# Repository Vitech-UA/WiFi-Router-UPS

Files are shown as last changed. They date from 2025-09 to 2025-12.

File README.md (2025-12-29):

# WiFi-Router-UPS
**Версія:** 3  
**Призначення:** Резервне живлення для WiFi-роутера та оптоволоконного терміналу (ONT)  
**Оновлення:** Версія 3 розроблена з урахуванням недоліків, виявлених у версії 2  

---
## Технічні характеристики
- **Вхідна напруга:** 8–12 В DC  
- **Максимальний вхідний струм:** 2 А  
- **Тип акумуляторів:** Li-Ion 18650 — 4 шт.  
- **Струм заряджання акумуляторів:** до 2,1 А  

### Вихідні канали
| Канал | Напруга | Струм | Призначення |
|---|---|---|---|
| 1 | 9 В / 12 В | до 1 А | Живлення WiFi-роутера |
| 2 | 9 В / 12 В | до 1 А | Живлення оптоволоконного терміналу |

---
## Зображення плати (v3)
| Верхня сторона (TOP) | Нижня сторона (BOTTOM) |
|---|---|
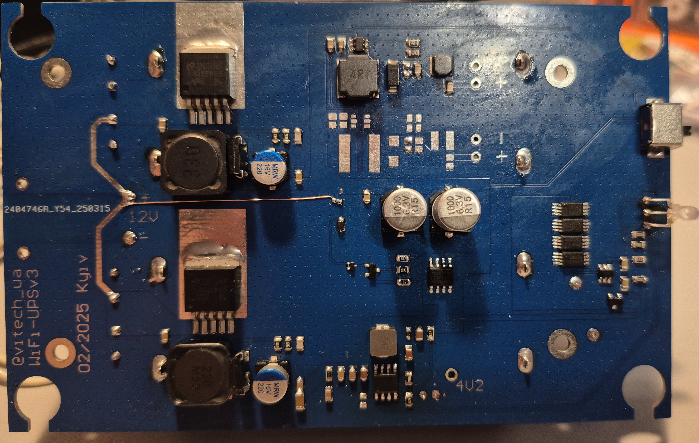
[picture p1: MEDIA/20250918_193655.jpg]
Top View
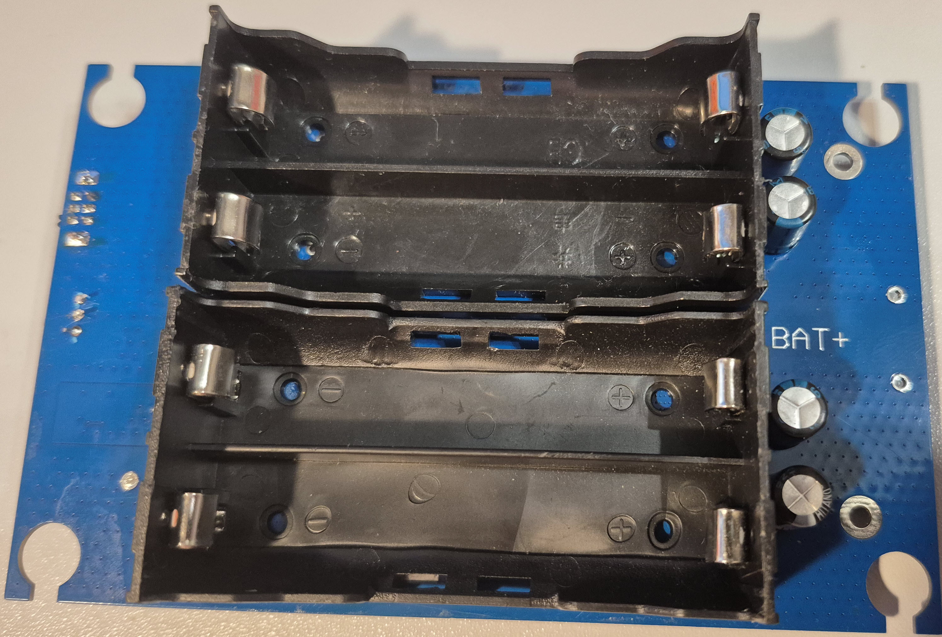
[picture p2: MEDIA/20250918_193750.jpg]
Bottom View
|  |  |

---
## Тестування системи
1. **Живлення зарядного пристрою (DC-DC 5 В) під навантаженням:**  
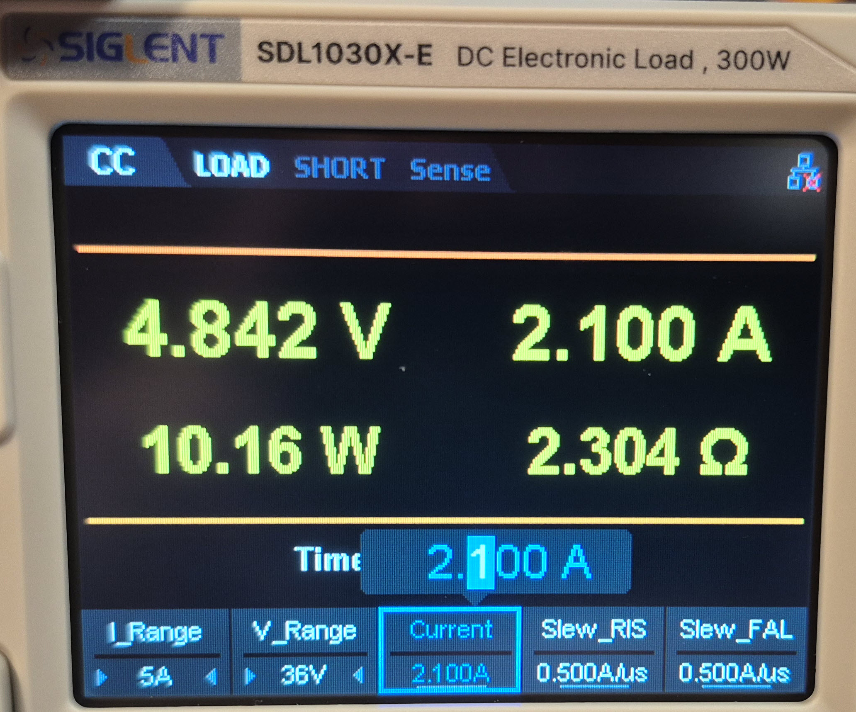
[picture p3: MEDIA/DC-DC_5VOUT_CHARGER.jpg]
   

2. **Живлення каналів через DC-DC перетворювач (5 В) під навантаженням:**  
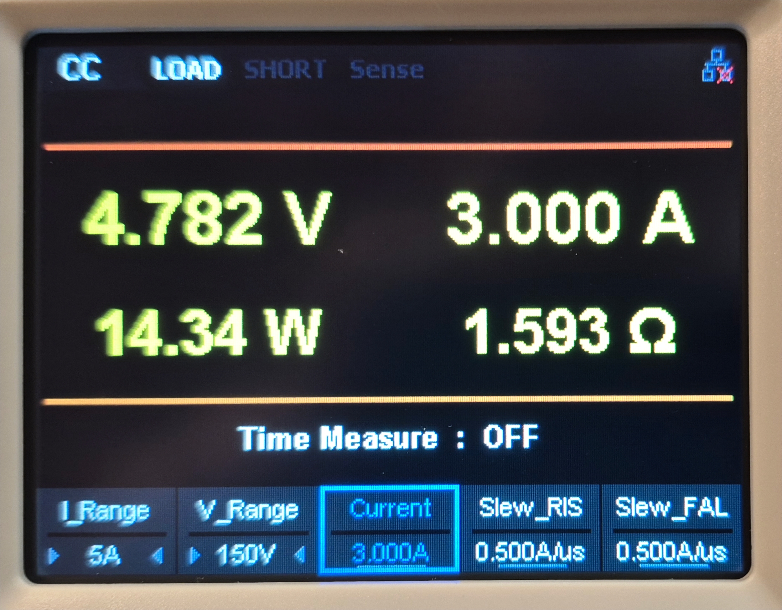
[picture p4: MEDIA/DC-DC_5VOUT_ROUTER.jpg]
   

3. **Підвищуючий перетворювач (5 В → 12 В) для каналів живлення під навантаженням:**  
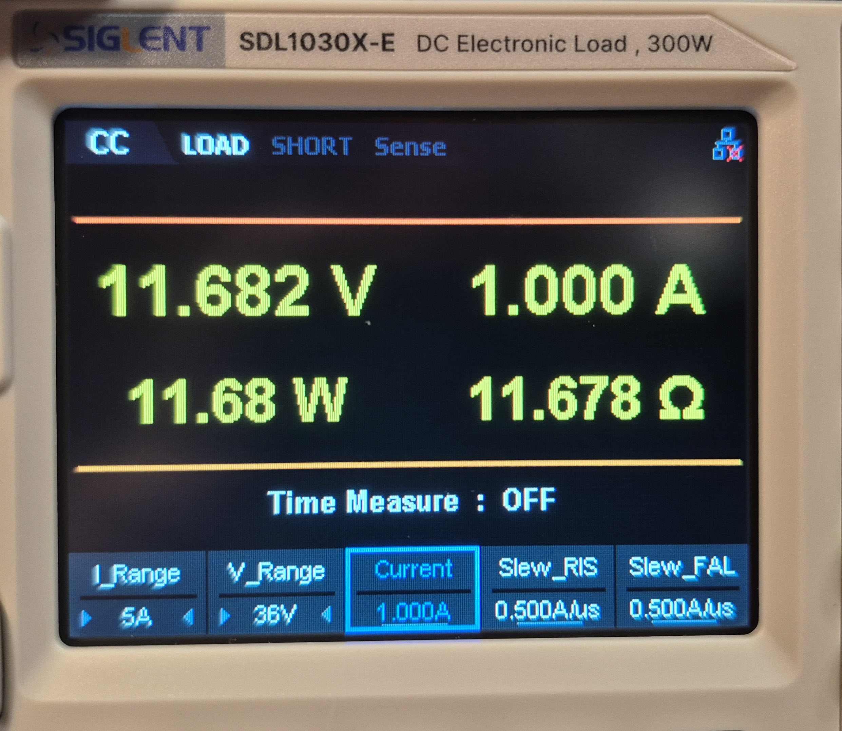
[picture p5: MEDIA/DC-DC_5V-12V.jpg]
   

---
## Критичні помилки плати (v3)
> **Усунення обов’язкове перед серійним виготовленням.**  
> (Приклад неправильного монтажу видно на фото верхньої сторони плати — TOP)

1. **Неправильне підключення стабілітрона VD3:**  
   Сигнал перемикання рекомендується брати з вхідних контактів.  
   - **Катод** VD3 підключити до **бази VT2**.  
   - **Анод** VD3 підключити до **землі (GND)**.

2. **Відсутній ланцюг керування транзистором VT2:**  
   Сигнал перемикання рекомендується брати з вхідних контактів.  
   - Через **резистор R15** з’єднати контакт **12V+** з **базою VT2** та **катодом VD3**.

3. **Монтаж діодів VD1 (SK56):**  
   - Через брак простору діоди тимчасово встановлені **лежачи на боці** (видно на фото верхньої сторони).  
   - Рекомендується використовувати корпус **SMC** (наприклад, тип: [SK56-7](https://imrad.com.ua/ua/sk56-7)).

---
## Рекомендації до версії 4 (не критичні)
1. Встановити конденсатори 330 мкФ / 25 В **[LOW ESR](https://imrad.com.ua/ua/eeefk1c331p-4)** на виходи DC-DC модулів на базі LM2596.  
2. Встановити дроселі 33 мкГн (3–4 А) у DC-DC модулях на базі LM2596.  
3. Перемикач живлення підключити до виводів **EN** DC-DC модулів на базі LM2596.  
4. Додати посадочні місця для резисторів конфігурації MT3608, щоб вибір вихідної напруги (9 В / 12 В) здійснювався запаюванням відповідного резистора.  
5. Встановити SMD-запобіжник у лінії живлення **4,2 В** від акумуляторів.  
6. Оновити шовкографію: додати позначення (десигнатори) компонентів та маркування полярності/призначення.  
7. Закласти посадочні місця для діодів SK56 у корпусі **SMC**.

---
## Плата v4
На основі вказаних вище рекомендації було оновлено пристрій до v4
+ Додано тестові пади -> v4.1
**3D-візуалізація плати (TOP):**  
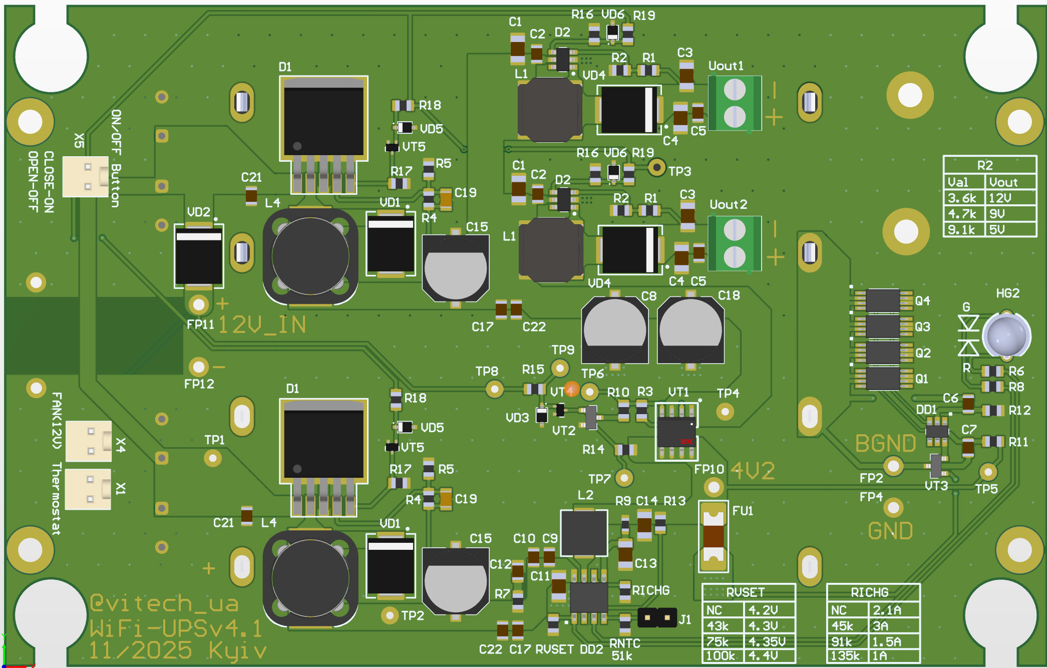
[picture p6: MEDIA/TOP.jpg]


**Зібрана плата v4:**  
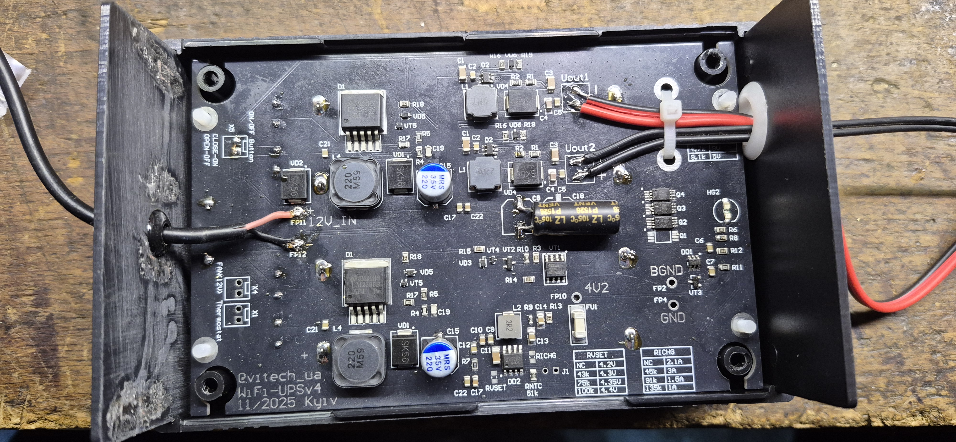
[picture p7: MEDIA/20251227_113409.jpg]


**Тестування плати v4:**  
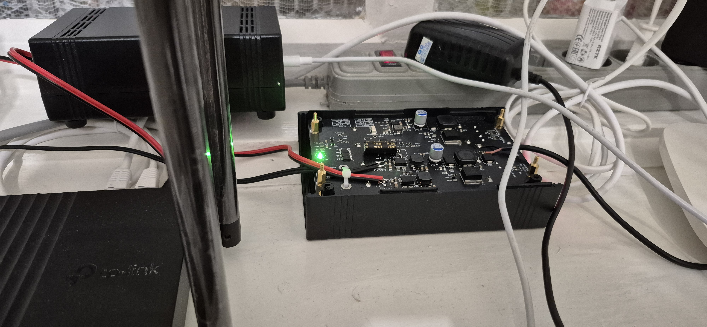
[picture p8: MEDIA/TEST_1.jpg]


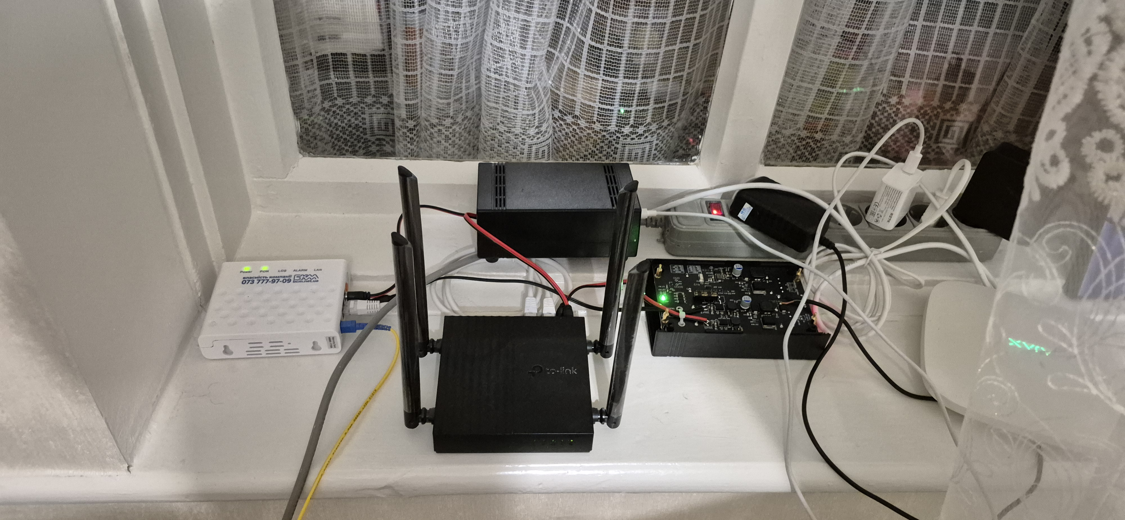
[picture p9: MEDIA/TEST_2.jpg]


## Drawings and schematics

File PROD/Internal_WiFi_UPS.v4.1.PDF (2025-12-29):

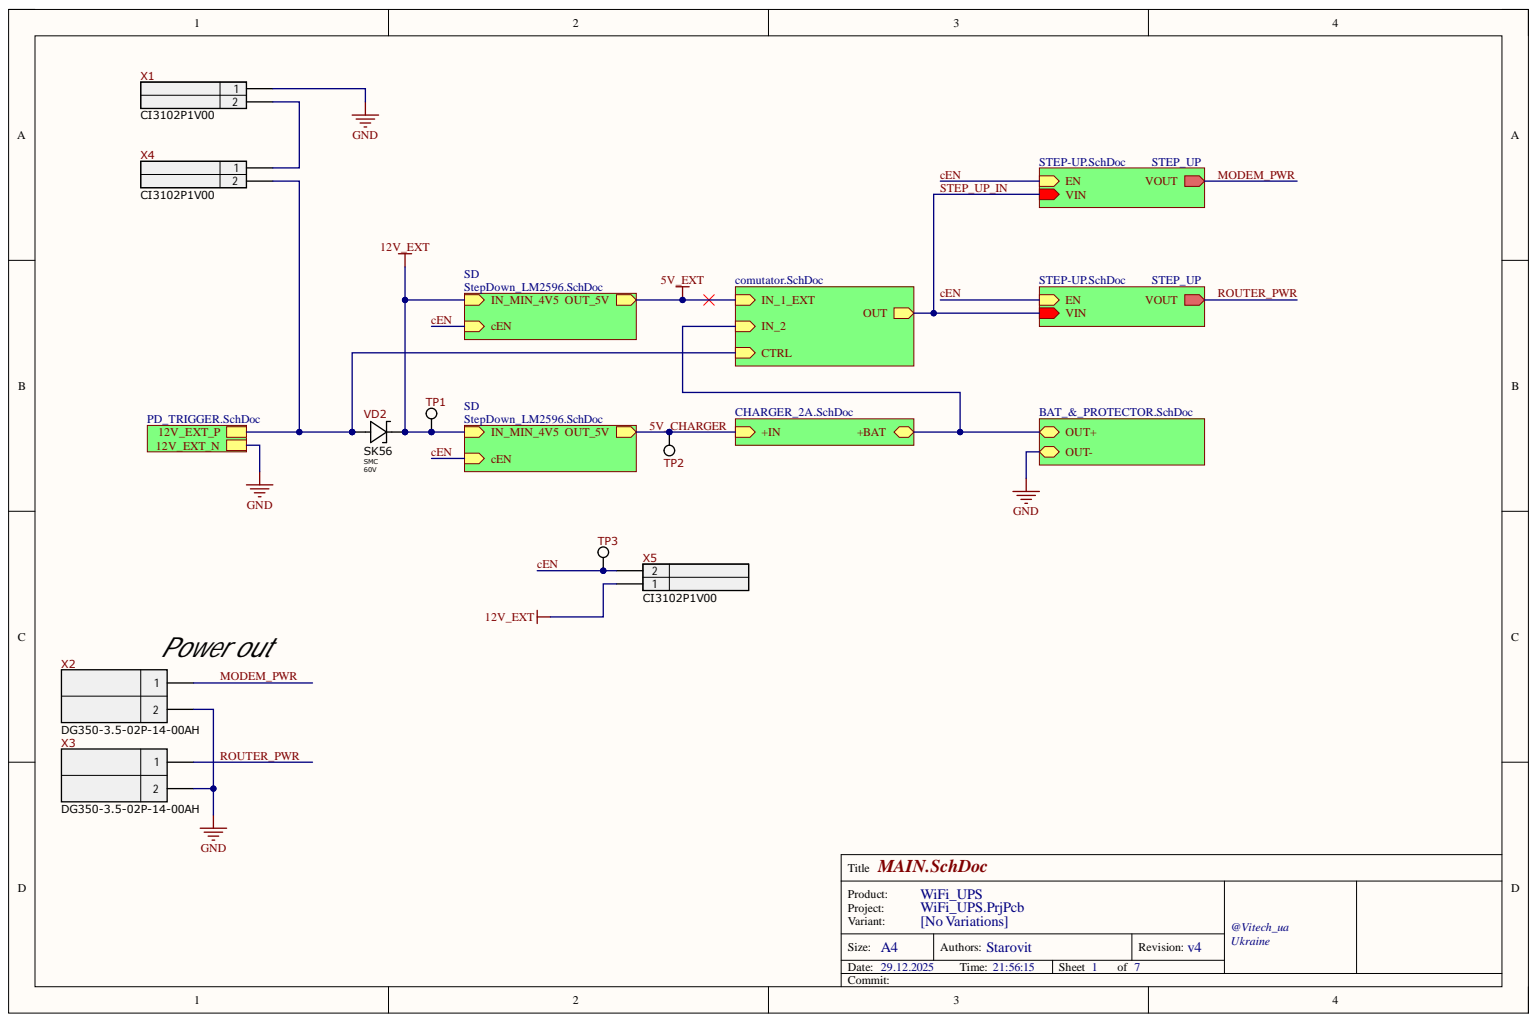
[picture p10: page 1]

IN_1_EXT OUT IN_2 | | EN VOUT VIN

CTRL

cEN

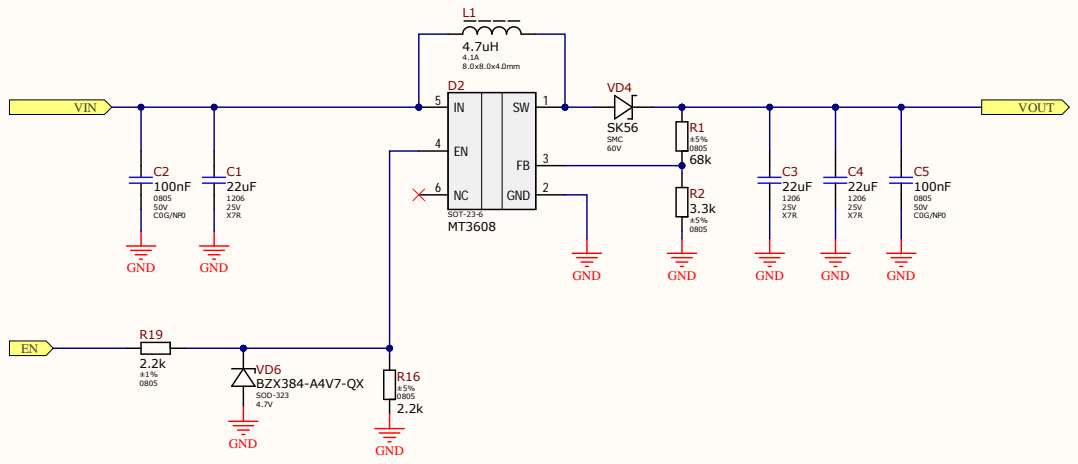
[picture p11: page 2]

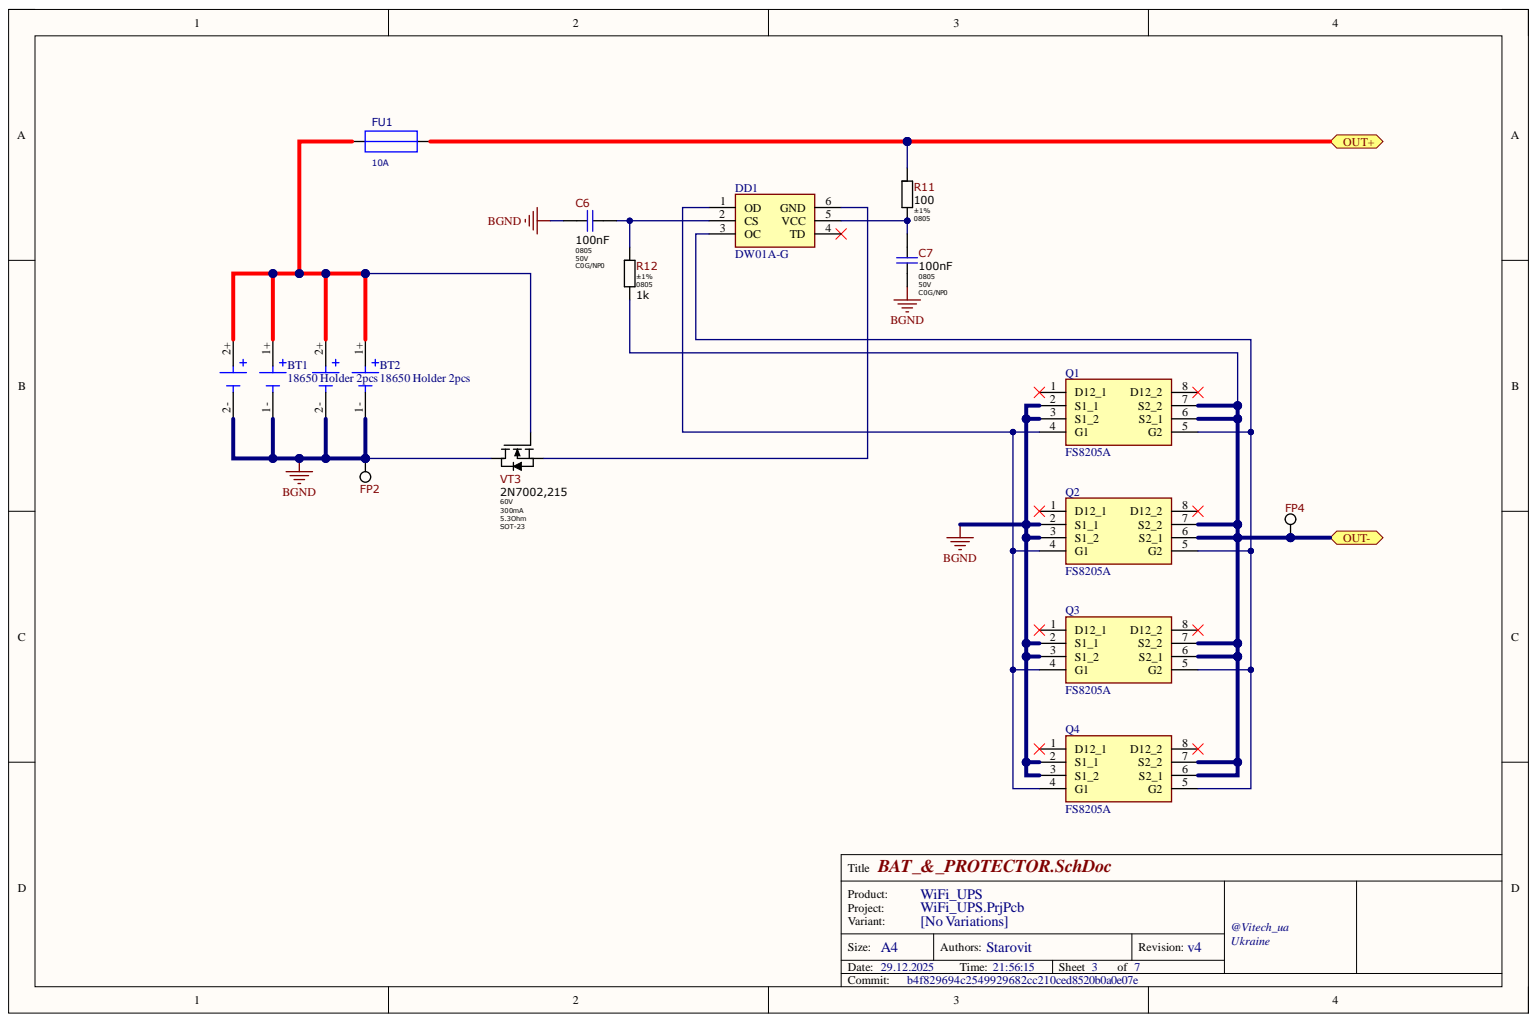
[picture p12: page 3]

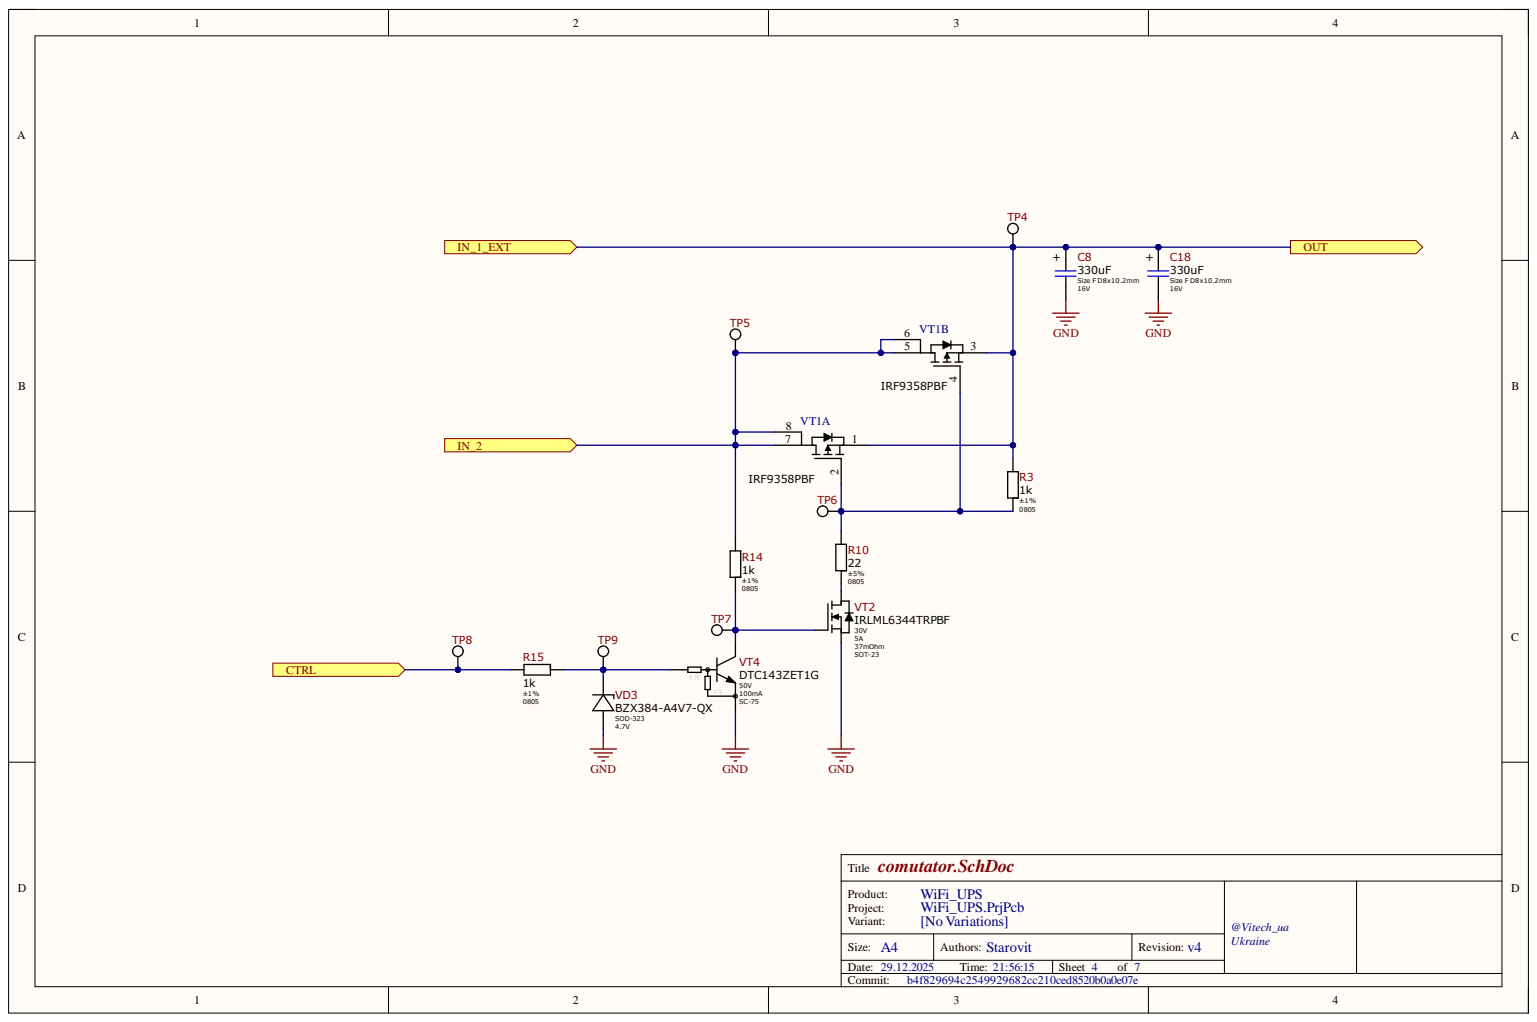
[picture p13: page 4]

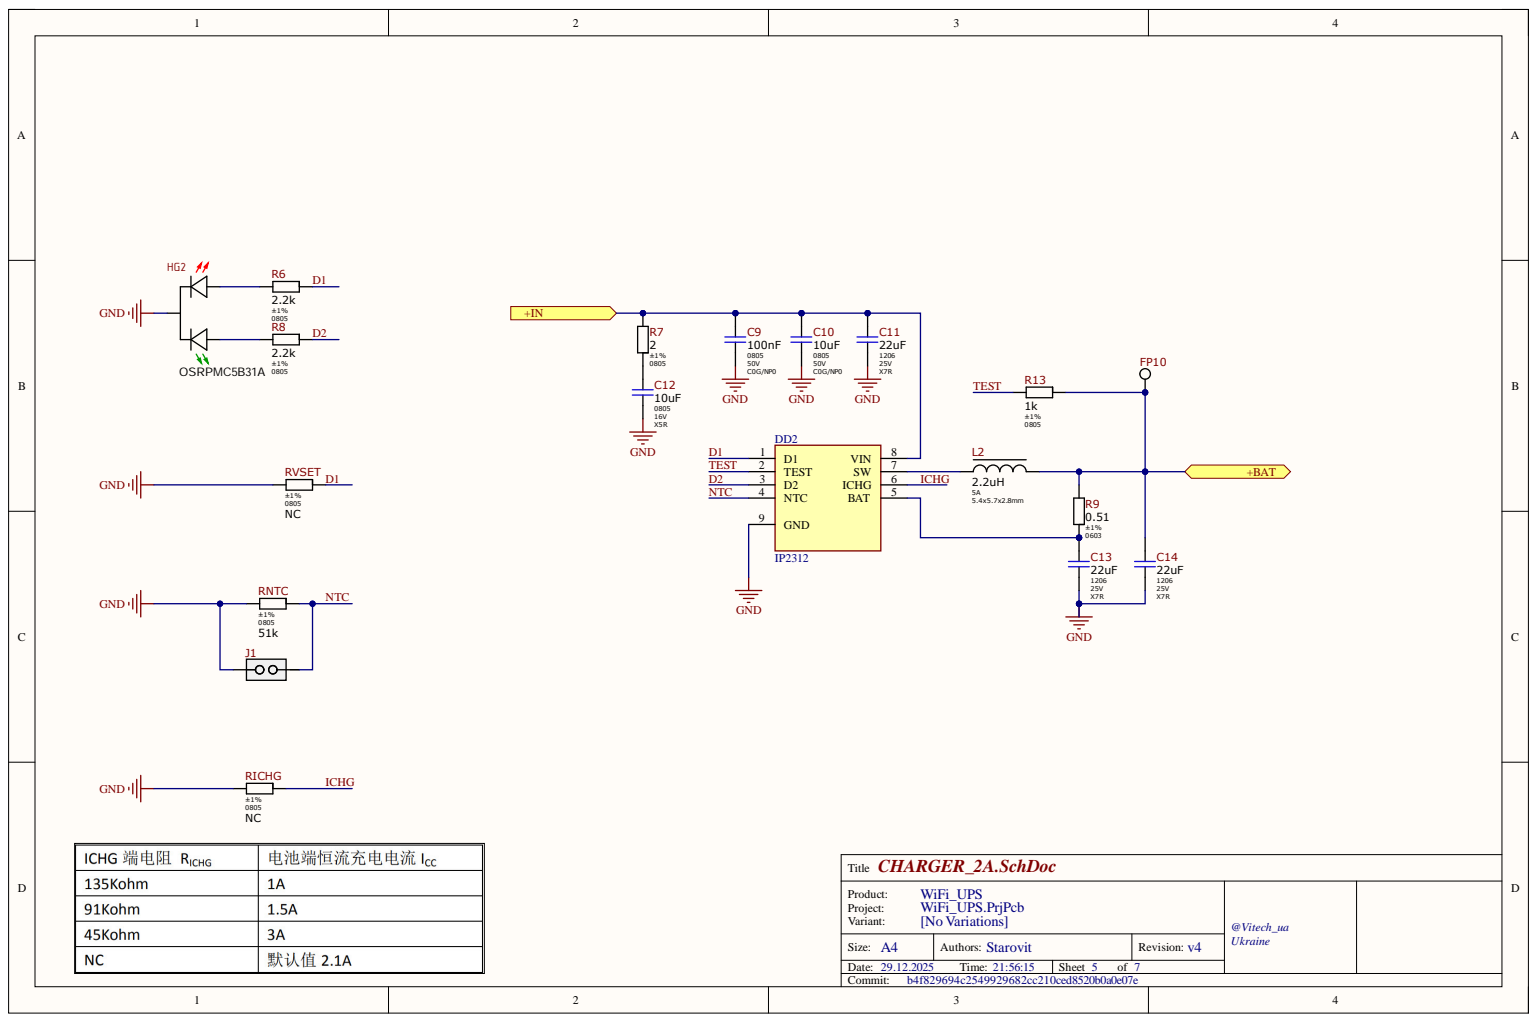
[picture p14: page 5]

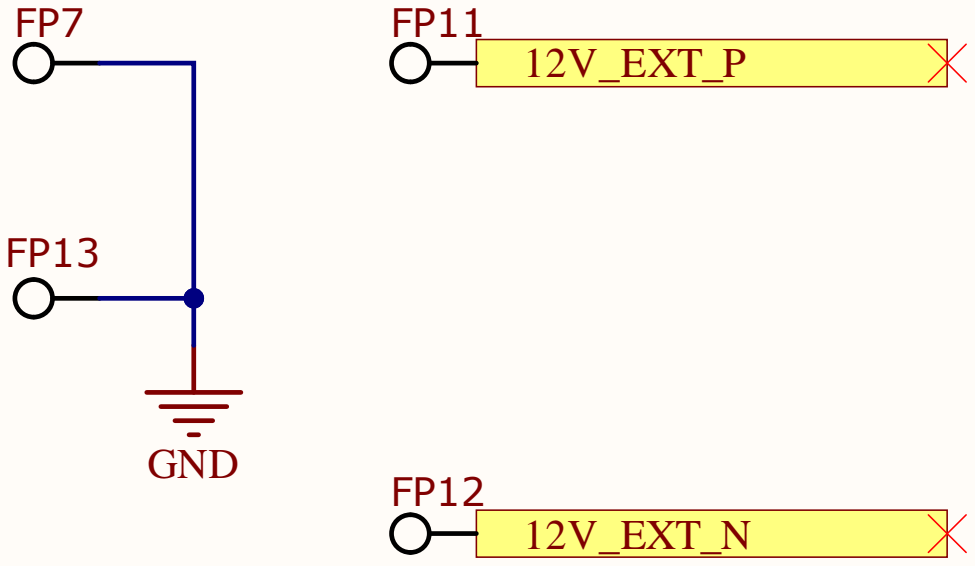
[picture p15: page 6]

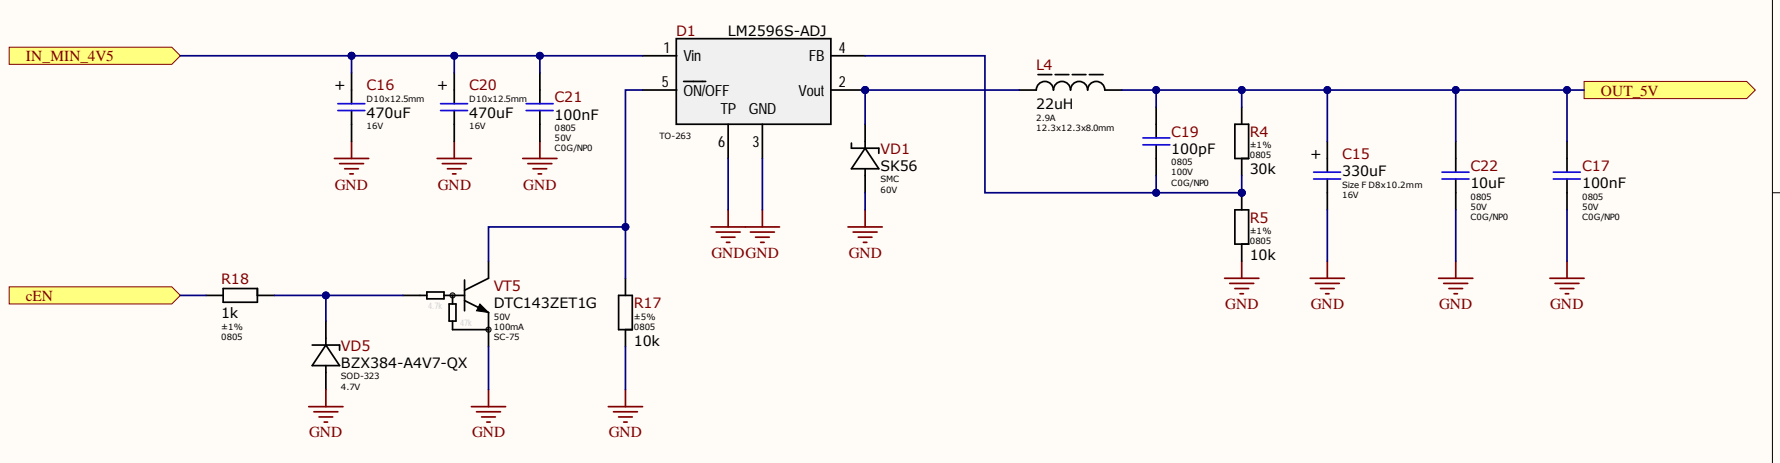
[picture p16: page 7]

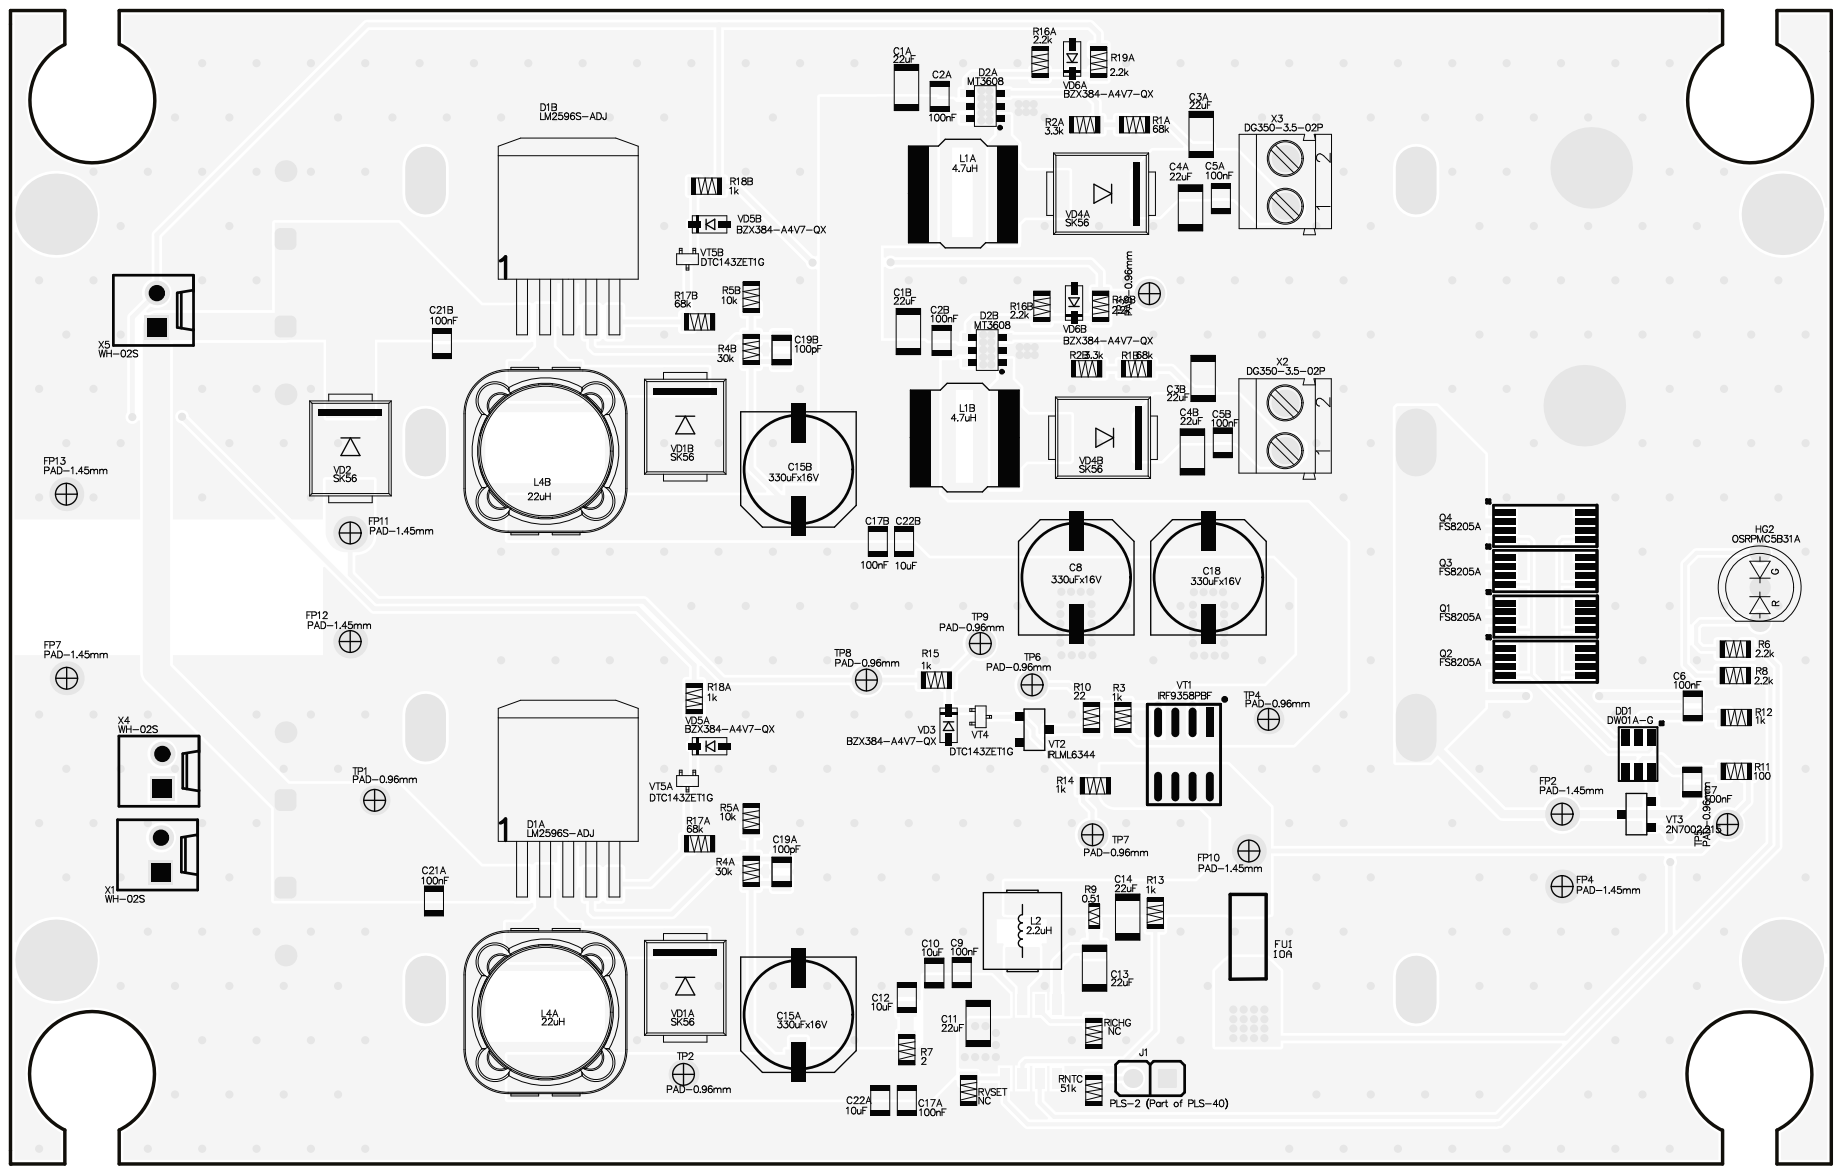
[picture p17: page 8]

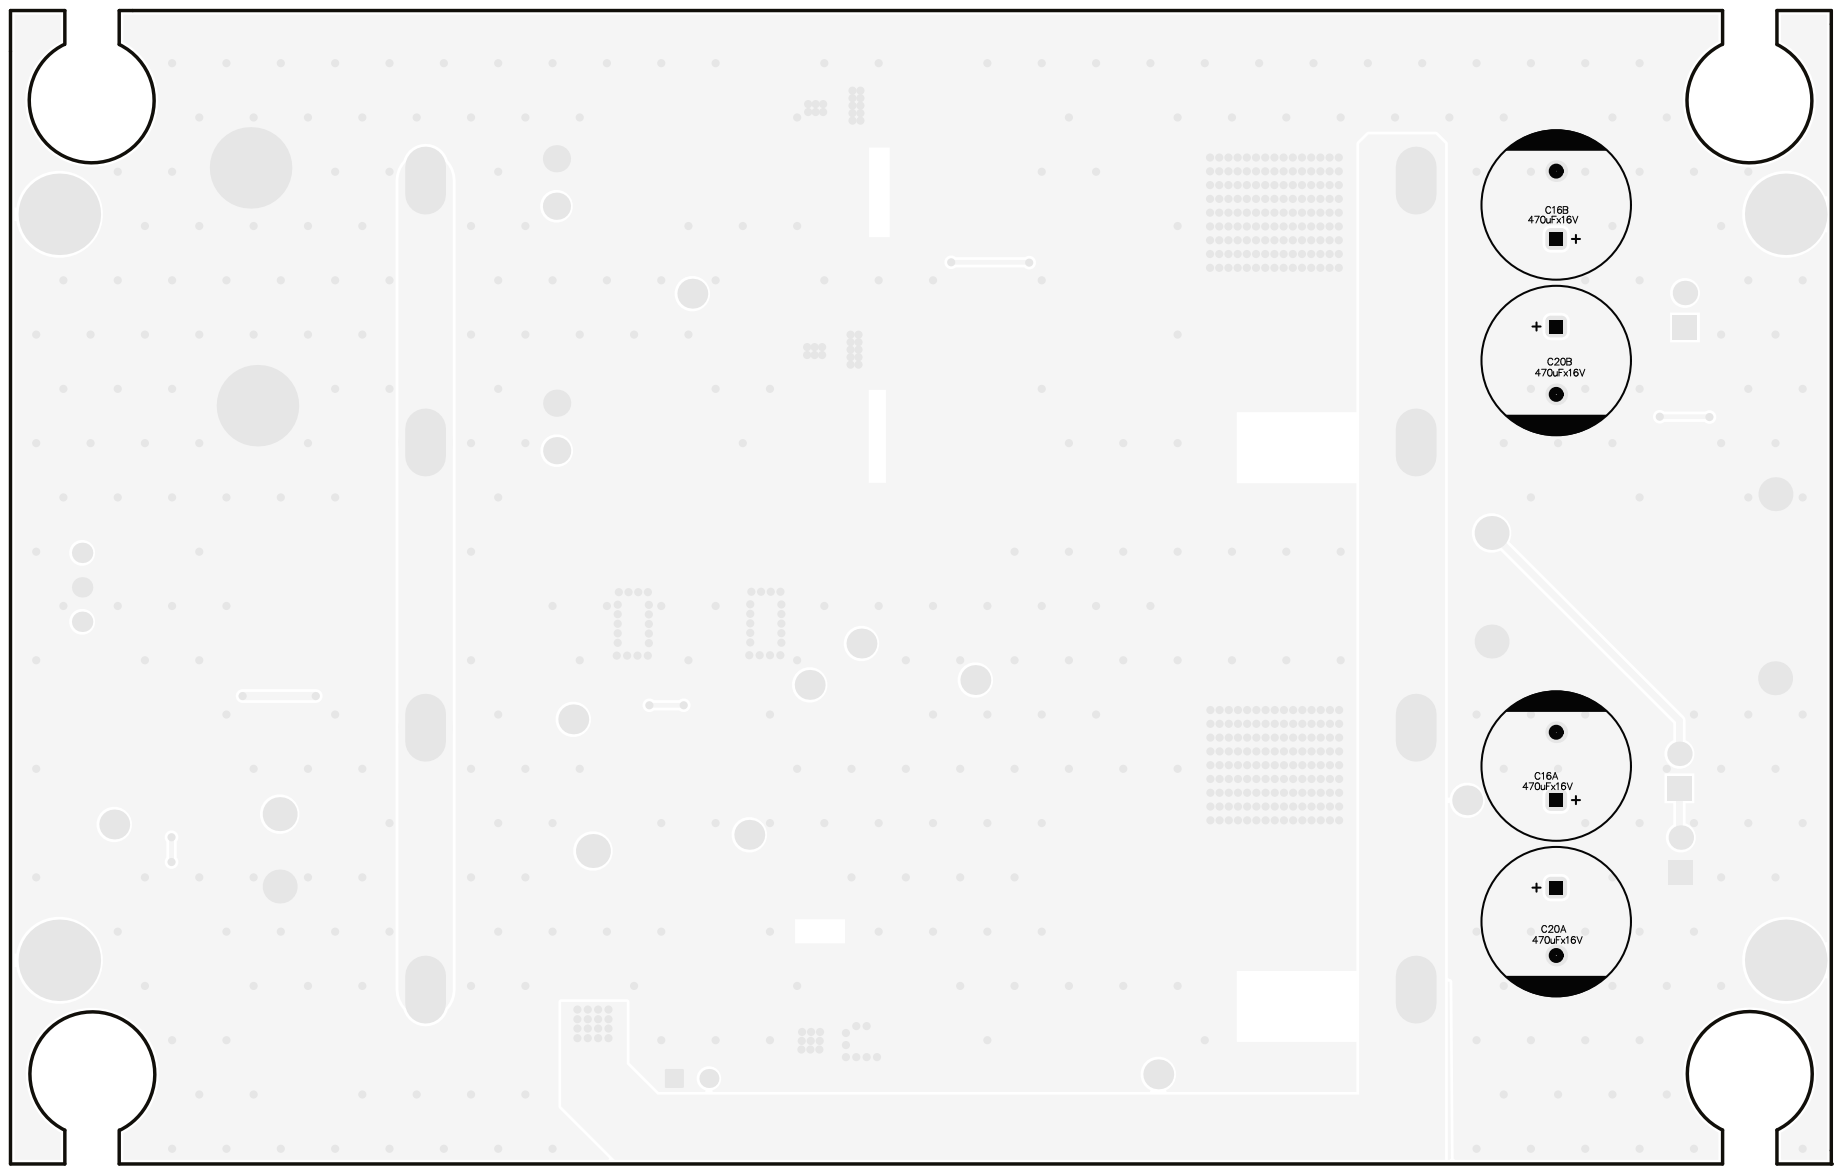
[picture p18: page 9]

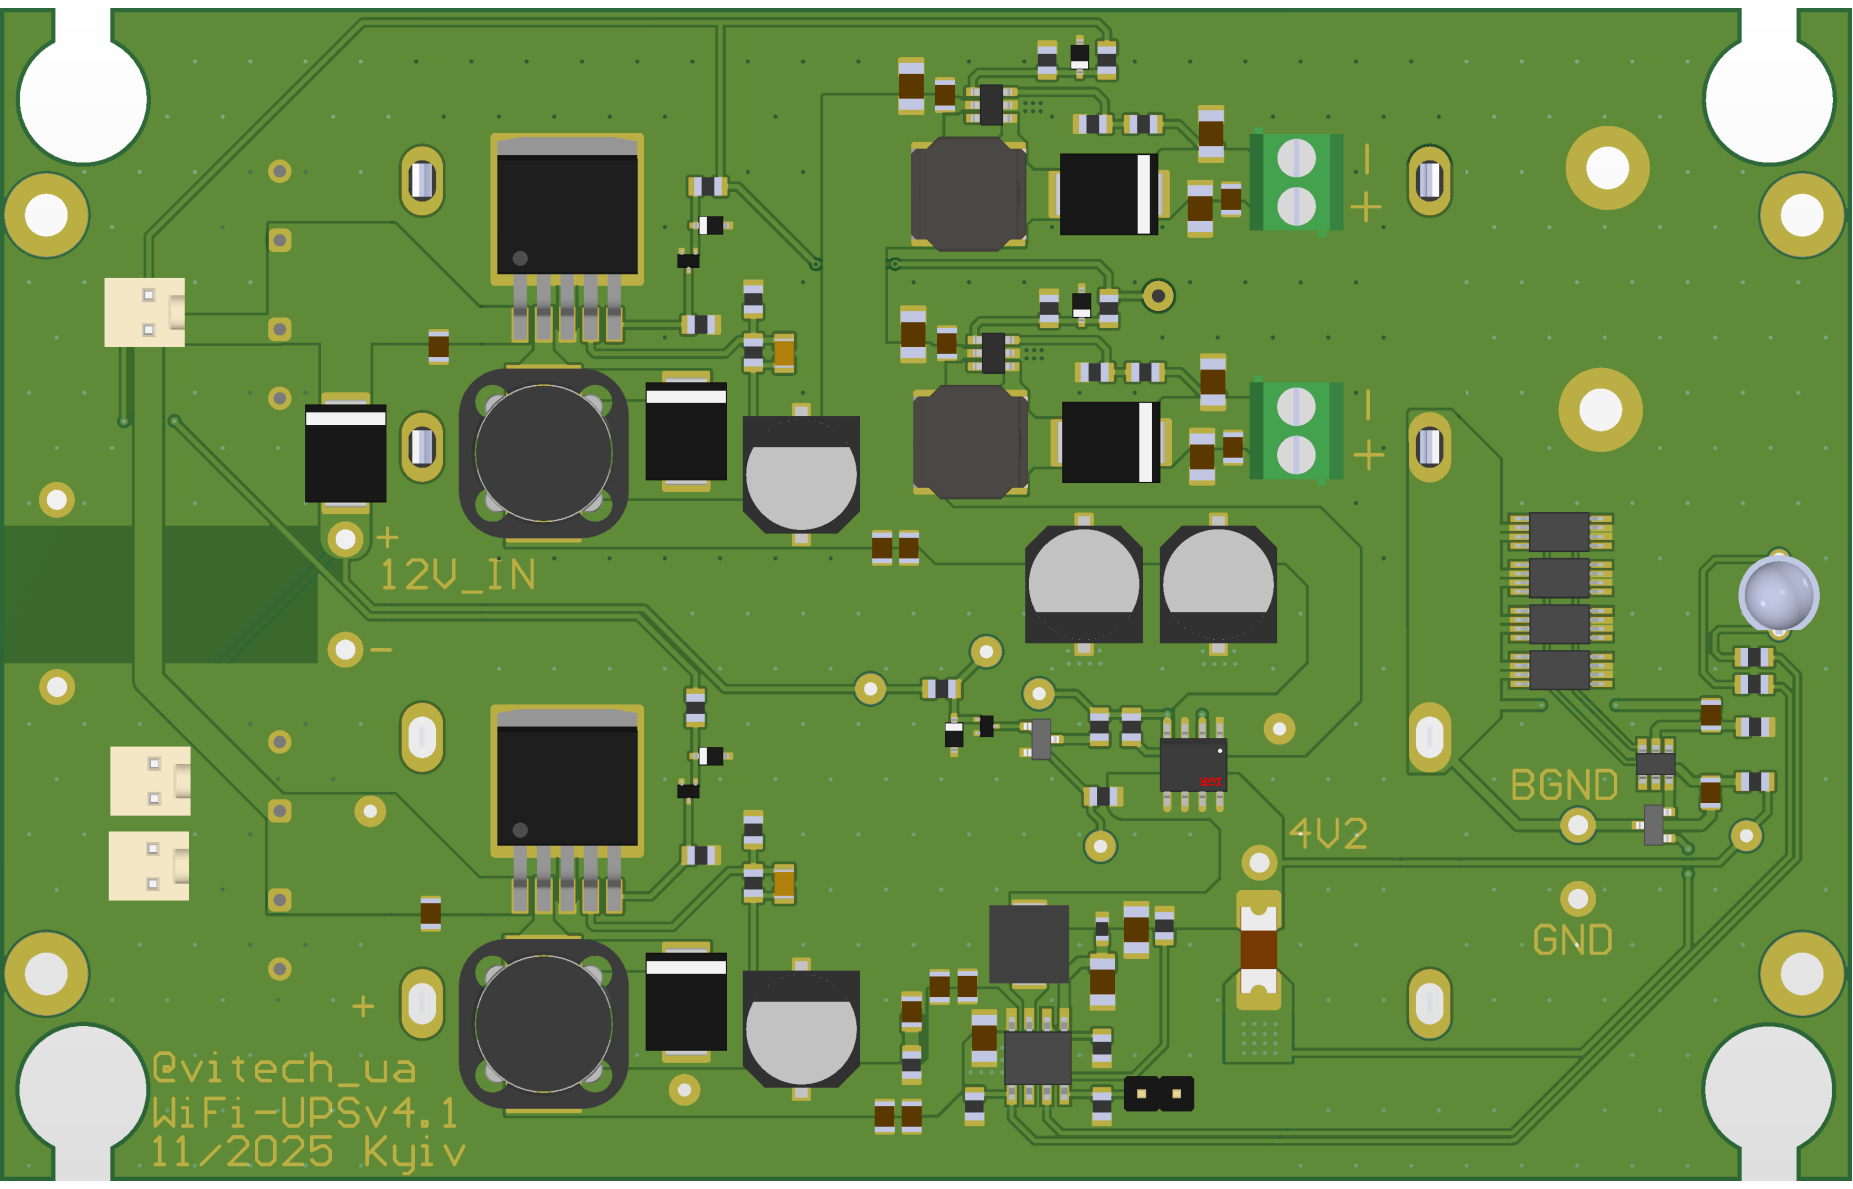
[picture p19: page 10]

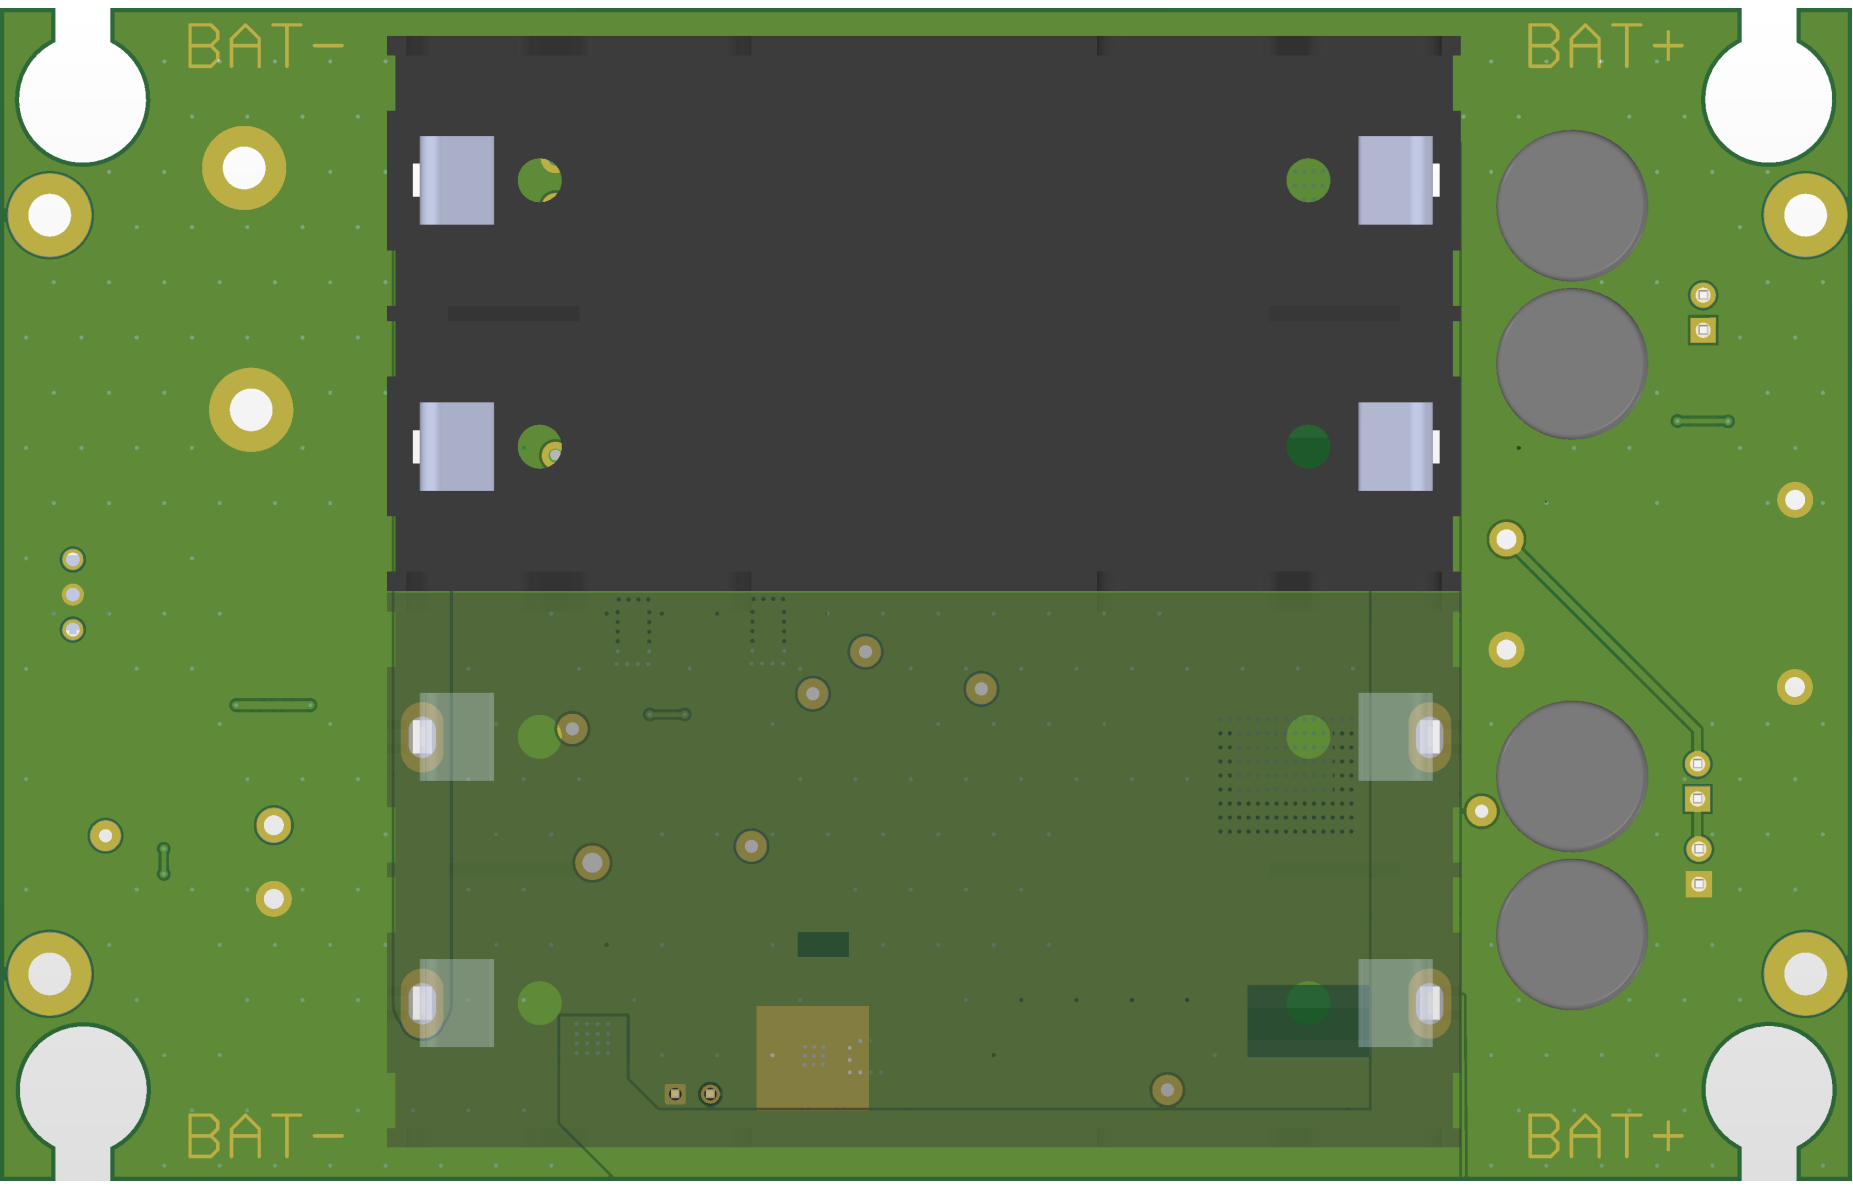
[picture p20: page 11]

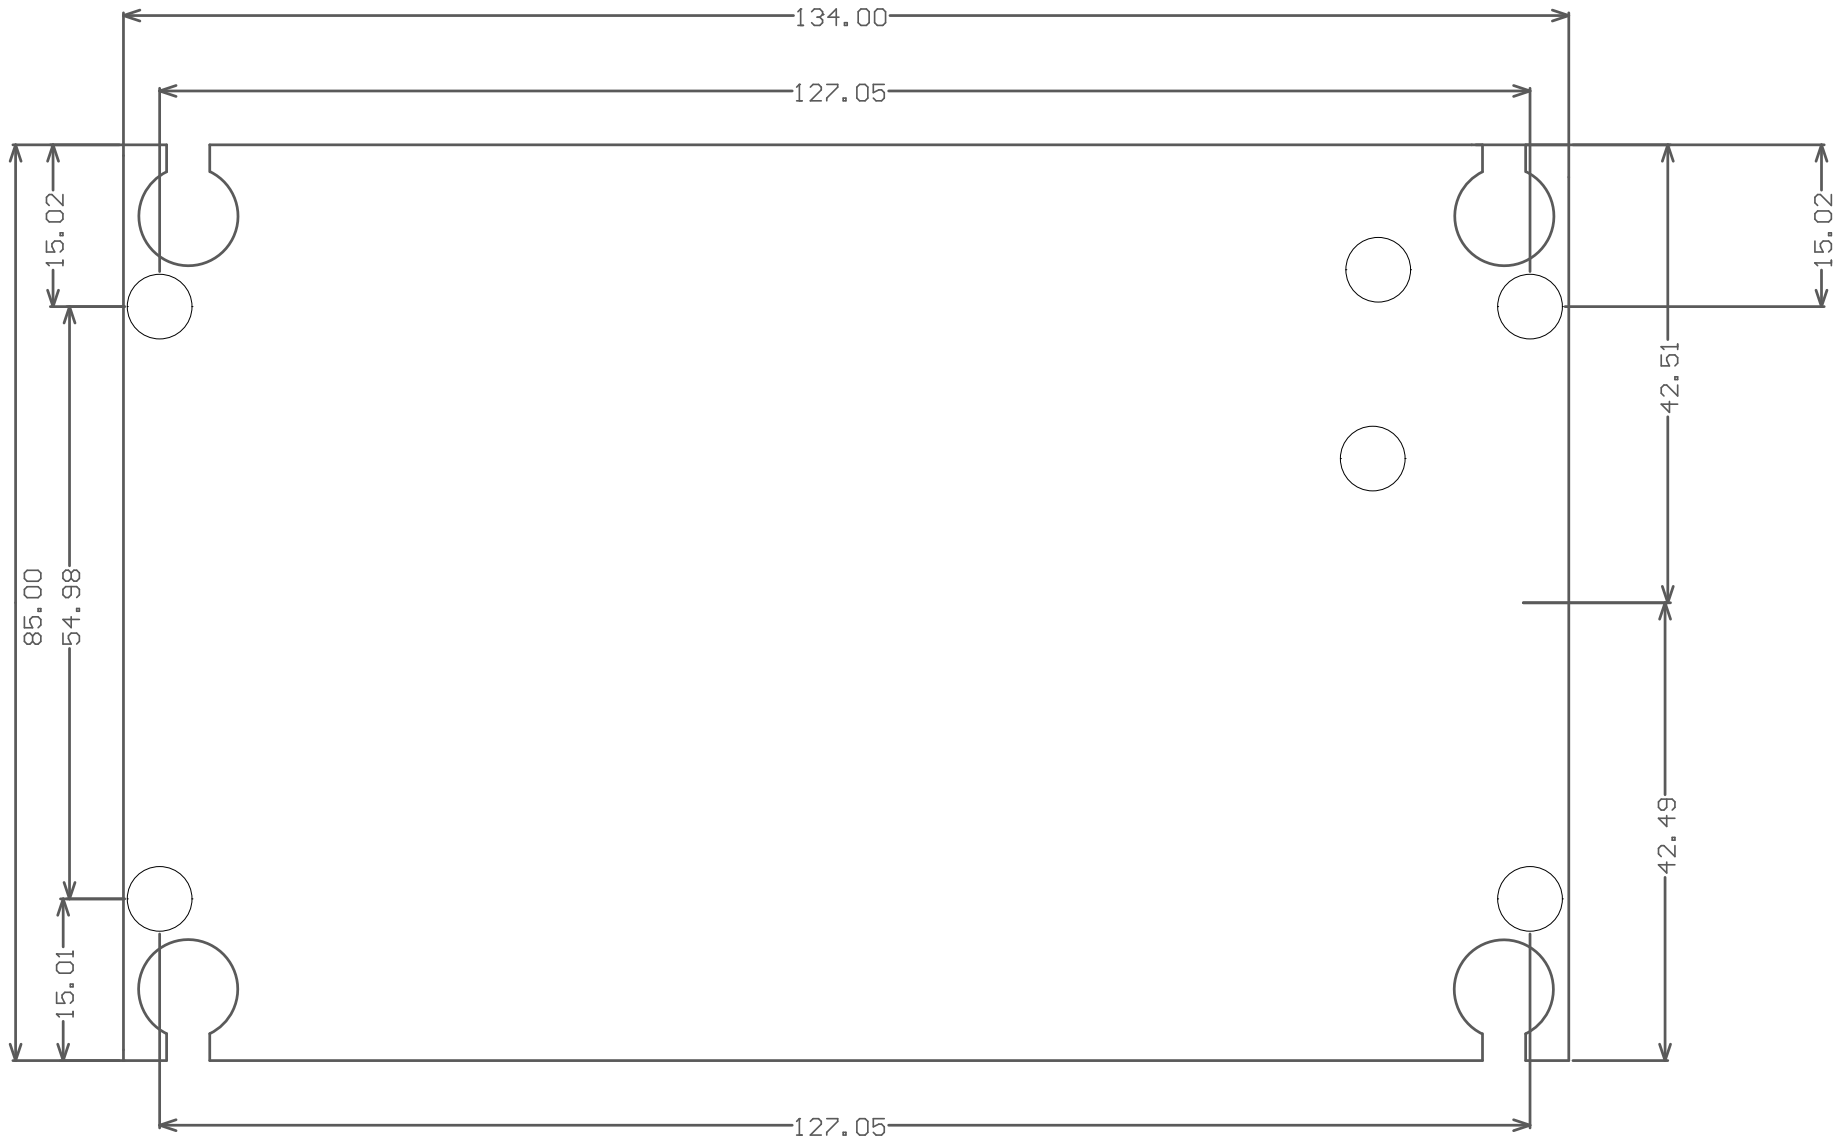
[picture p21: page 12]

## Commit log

2024-06-23 Світлодіод індикації вихідного живлення.
    [main.SchDoc]
2024-07-01 Захист АККК
    [CHARGER.SchDoc, main.SchDoc]
2024-12-08 Невеличкий ренеймінг і чистка
    [BAT_&_PROTECTOR.SchDoc, CHARGER_2A.SchDoc, MAIN.SchDoc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]
2025-01-25 Додав: Захист від переполюсовки для DW01A, Вимикач живлення, Розставив десигнатори + коменти
    [BAT_&_PROTECTOR.SchDoc, CHARGER_2A.SchDoc, MAIN.SchDoc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]
2025-01-25 R6&R8 ->2k2
    [CHARGER_2A.SchDoc, pcb.PcbDoc]
2025-02-01 Комутатор тепер лише на здвоєному P-CH MOSFET
    [CHARGER_2A.SchDoc, MAIN.SchDoc, WiFi_UPS.PrjPcb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]
2025-02-16 Переніс title, Щоб не налазили на PCB
    [StepDown_LM2596.SchDoc, WiFi_UPS.PrjPcb, pcb.PcbDoc]
2025-03-14 Фікси перед виготовленням
    [BAT_&_PROTECTOR.SchDoc, CHARGER_2A.SchDoc, MAIN.SchDoc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]
2025-03-14 Оновлена структура проекту + згенерував BOM
    [Bill of Materials - WiFi_UPS.v3.xlsx]
2025-09-02 Прибрав не актуальний БОМ
    [Bill of Materials - WiFi_UPS.v3.xlsx, MAIN.SchDoc, pcb.PcbDoc]
2025-09-02 Перегенерував адекватний BOM
    [Bill of Materials - WiFi_UPS.v3.xlsx]
2025-09-03 Фікси перед брінгапом v3
    [BAT_&_PROTECTOR.SchDoc, Bill of Materials - WiFi_UPS.v3.xlsx, CHARGER_2A.SchDoc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]
2025-09-18 Додав фото
2025-09-18 +Скріни тестів під навантаженням
2025-09-23 Пофіксив на монтажці IRF9358 + DW01A
    [BAT_&_PROTECTOR.SchDoc, CHARGER_2A.SchDoc, WiFi_UPS.PrjPcb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]
2025-11-30 V4. Схема. Покращення проти V3
    [BAT_&_PROTECTOR.SchDoc, CHARGER_2A.SchDoc, MAIN.SchDoc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]
2025-11-30 PCB_V4_Розтрасував
    [BAT_&_PROTECTOR.SchDoc, CHARGER_2A.SchDoc, MAIN.SchDoc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]
2025-11-30 Згенерував гербер. Замовив плати.
    [Bill of Materials - WiFi_UPS.v3.xlsx, WiFi_UPS.PrjPcb, pcb.PcbDoc]
2025-12-18 Правки
    [MAIN.SchDoc, Калькуляція комплектуючих.xlsx]
2025-12-29 Додав тестові точки. v4.1
    [MAIN.SchDoc, WiFi_UPS.PrjPcb, comutator.SchDoc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]
2026-01-05 Додав калькуляцію комплектуючих.
    [Калькуляція комплектуючих.xlsx, Калькуляція покупних комплектуючих WiFi_UPS_v4.xlsx]
